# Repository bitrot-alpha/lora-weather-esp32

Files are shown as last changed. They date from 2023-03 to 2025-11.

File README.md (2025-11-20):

# lora-weather-esp32
Weather station with ESP32 and LoRa

This weather station is capable of measuring wind speed and direction, total rainfall, and current environmental conditions. Conditions include temperature, humidity, and barometric pressure. I put this together because I got interested in microclimate weather. Many rural areas in the United States do not have a weather station nearby, so the conditions you experience may not match what is shown on https://www.weather.gov/ or AccuWeather since the weather station may be over 20 miles away from you. A popular commercially available version of this project is the Ambient Weather WS-2902 (retail: $200 US). However, Ambient Weather does not publish what specific sensors they use in their product, so accuracy is questionable. The wireless range of the sensing unit to the "console" is also on the low end, about 300ft line of sight. On the higher end, there is the KestrelMet 6000 series (starting at $800 US) of stations which is more in line with the capabilities of this project with the option for LTE connectivity (overkill for my purposes).

The system consists of a base station outside where all the sensors are mounted, and a receiver unit that displays the current reading on an LCD. The receiver also connects to wifi and serves a basic webpage with current readings. Webpage (local network only) at http://weather-station.local/

### Current Features
* Atmospheric conditions
  * Temperature - +/-0.5C (BME280)
  * Relative Humidity - +/-2% (SHT31-D)
  * Barometric Pressure - +/- 1.5Pa/K (BME280)
* Wind Speed & Direction (cup-type anemometer, 16 direction weather vane)
* Accumulated Rainfall (tipping bucket type) - seems to be highly accurate. I am getting comparable data to my local weather station. The mounting is susceptible to vibration, so the mast needs to be solidly anchored.
* Self-powered base station
  * 2 watt solar "array"
  * 3000mAh/11Wh battery
  * The only outages I have gotten with this configuration are from user error (forgetting to plug back in the solar panel wires). Have not gotten a dead battery from overcast/rainy days yet.
* Long range wireless connection (untested for "max range" but since this is Arduino, we can configure for more power/signal robustness if needed)
* **NEW** view current weather data from web browser (November 2025)
### Planned Additions (Wishlist)
* ~~Add SHT31 sensor for more accurate humidity data. The BME280 is not designed for "condensing" environments (don't get it wet..)~~ SHT31-D installed
  * Document waterproofing methods for the electronics
* Historical data with LittleFS storage. Store a week or more of data.
* Graph the data via web browser. Possible with a library like [Chart.js](https://www.chartjs.org/)
* Add more configuration capability over LoRa
  * Send calibration commands from indoor receiver
  * Set the time with NTP. Have the data reset at 3AM instead of whenever system reset + 48hrs have passed.

## Hardware
* [MCU Board][mcu] - Heltec WiFi LoRa 32 v3 (ESP32-S3 with SX1262 LoRa modem and SSD1306 0.96" OLED Display)   
* Wind Speed, Wind Direction, and Rain Gauge kit - Available from [Argent Data][argent data kit] or [SparkFun][sparkfun kit].  
* [HiLetGo BME280 breakout board][bme280 board] - measures temperature, humidity, and pressure. The humidity sensor on this device failed after a year (not meant for condensing environments, i.e. fog). If you're building a project like this, go with the cheaper BMP280.
* [HiLetGo SHT31-D breakout board][sht31 board] - measures temperature and humidity. I added it just for the humidity sensing. I suppose according to the specs, the SHT is more accurate for temperature too.
* [DFRobot MPPT 6V Solar Panel Controller][dfrobot board] - charges a LiPo battery with the help of the sun  
* [Ambient Weather Solar Shield/Stevenson Screen][atmo sensor housing] - I didn't want to 3D print anything major for this project, so I found this on Amazon.  
* [2x 5V 1W Solar Panel][solar panel]  
* [3.7V 3000mah LiPo battery][lipo battery]  
* [RJ11 Jack Breakouts][rj11 jacks] - The wind and rain sensor kit uses RJ11 connectors.  
* [Generic LCD2004A LCD module with I2C][lcd i2c module] - for the indoor display.  

[mcu]: https://heltec.org/project/wifi-lora-32-v3/
[sparkfun kit]: https://www.sparkfun.com/products/15901
[argent data kit]: https://www.argentdata.com/catalog/product_info.php?products_id=145
[bme280 board]: https://www.amazon.com/gp/product/B01N47LZ4P/
[sht31 board]: https://www.amazon.com/dp/B0CN32WXJY
[dfrobot board]: https://www.amazon.com/gp/product/B07MML4YJV/
[atmo sensor housing]: https://www.amazon.com/gp/product/B09T4QDBN3/
[solar panel]: https://www.amazon.com/dp/B0BML3PR4Z
[lipo battery]: https://www.amazon.com/dp/B0DK5BBKM5
[rj11 jacks]: https://www.amazon.com/dp/B09HTRKRSH
[lcd i2c module]: https://www.amazon.com/dp/B01GPUMP9C/

## Tools
* [PlatformIO IDE based on VS Code][platformio]   
* [For small tests: Arduino IDE][arduino]   
* [The wonderful RadioLib for using LoRa][radiolib]   
* [ESPAsyncWebServer][asyncwebserver]   

[platformio]: https://platformio.org/platformio-ide
[arduino]: https://www.arduino.cc/en/software
[radiolib]: https://github.com/jgromes/RadioLib
[asyncwebserver]: https://github.com/ESP32Async/ESPAsyncWebServer/wiki

## Photos
These are a bit old, so they don't reflect the most current setup. I have since modified the system with a larger 3000mAh lithium cell and added another solar panel for increased runtime. I *think* the charge should last for more than a couple overcast days now.
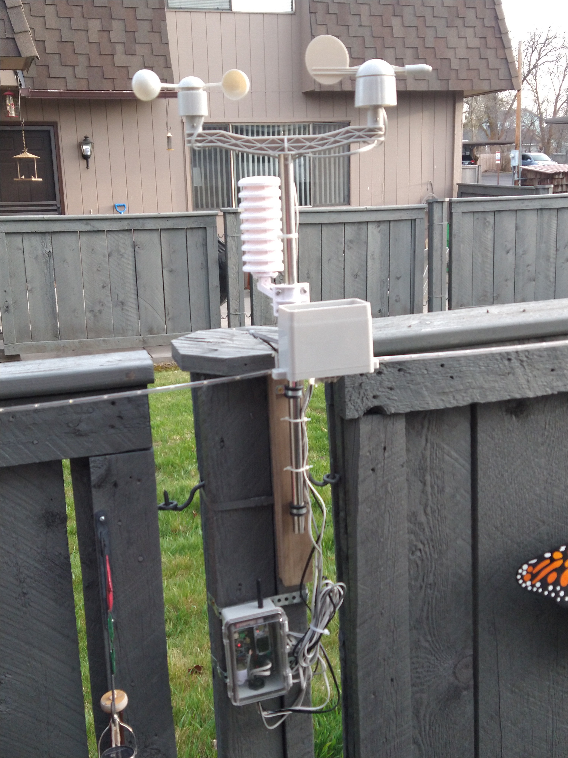
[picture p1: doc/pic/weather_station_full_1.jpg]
station1

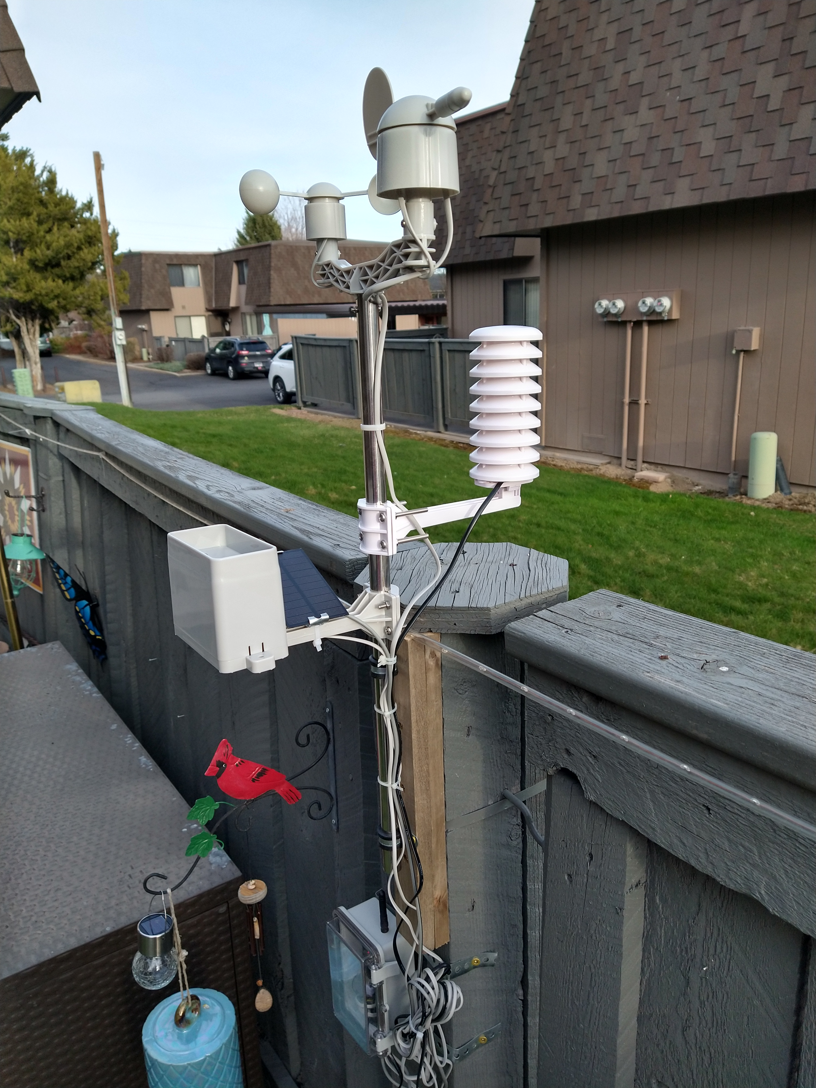
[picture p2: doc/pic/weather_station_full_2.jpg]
station2

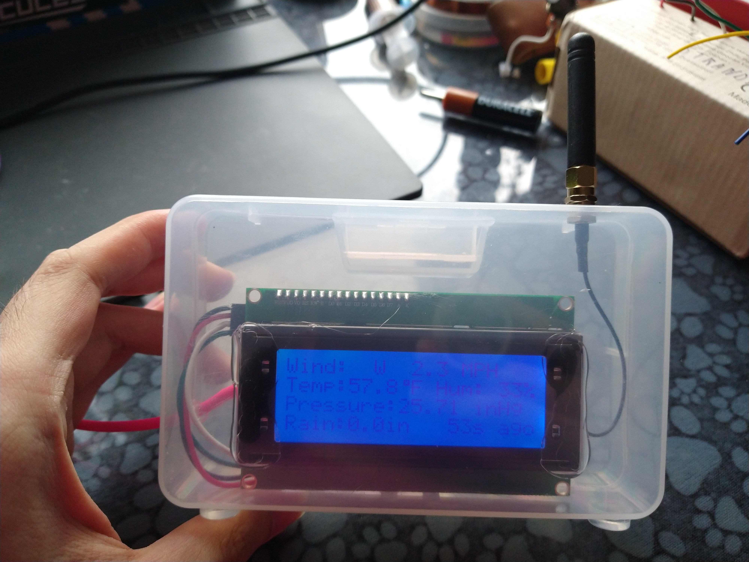
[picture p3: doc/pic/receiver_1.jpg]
receiver1

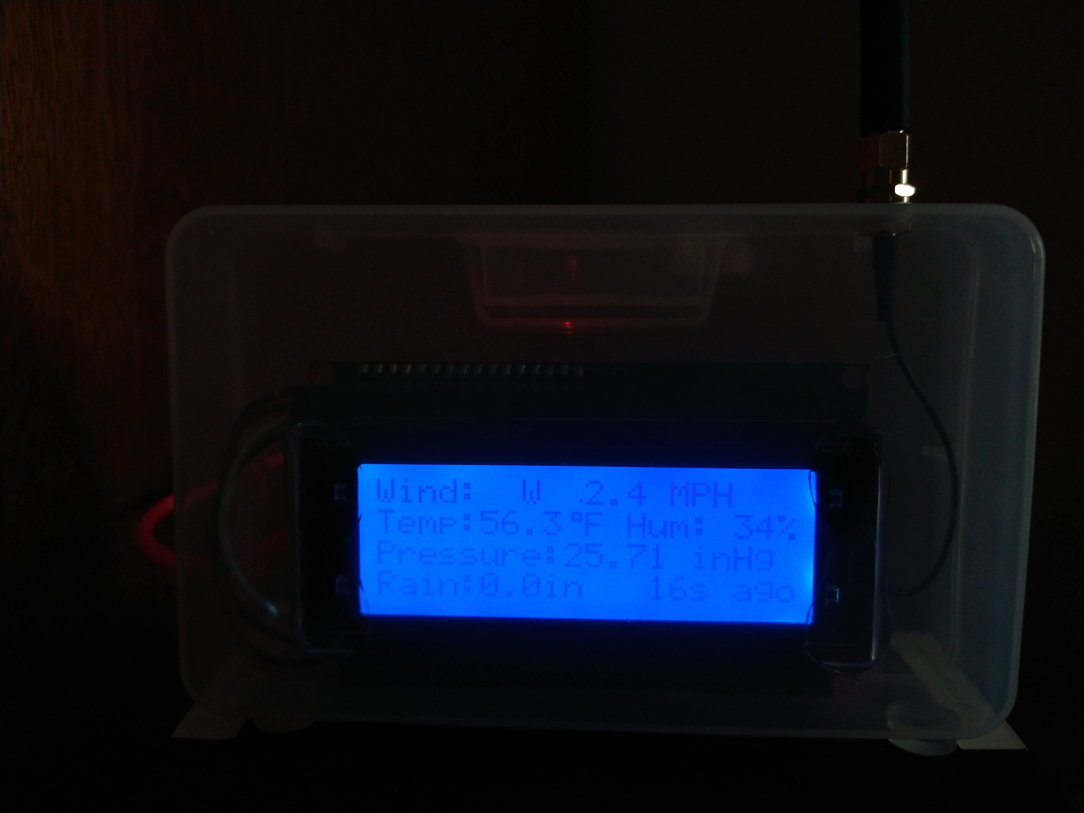
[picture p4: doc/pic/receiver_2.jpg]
receiver2

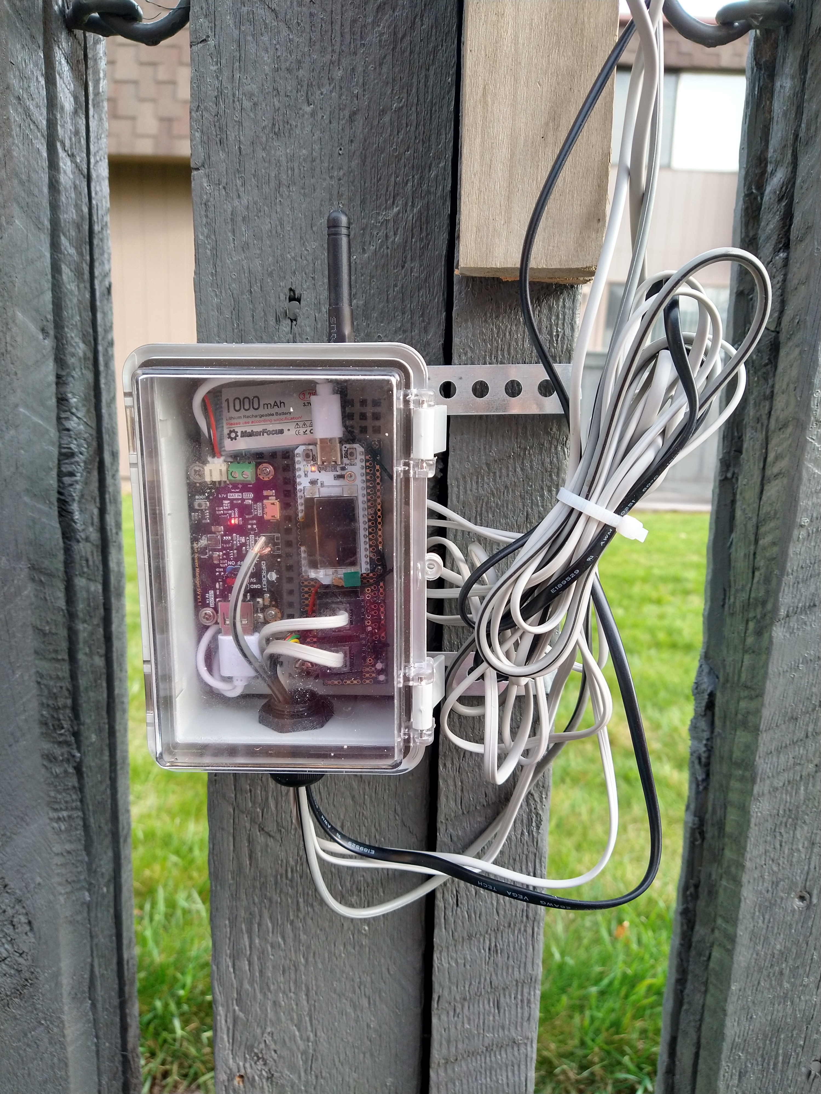
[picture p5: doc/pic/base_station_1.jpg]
bstation1

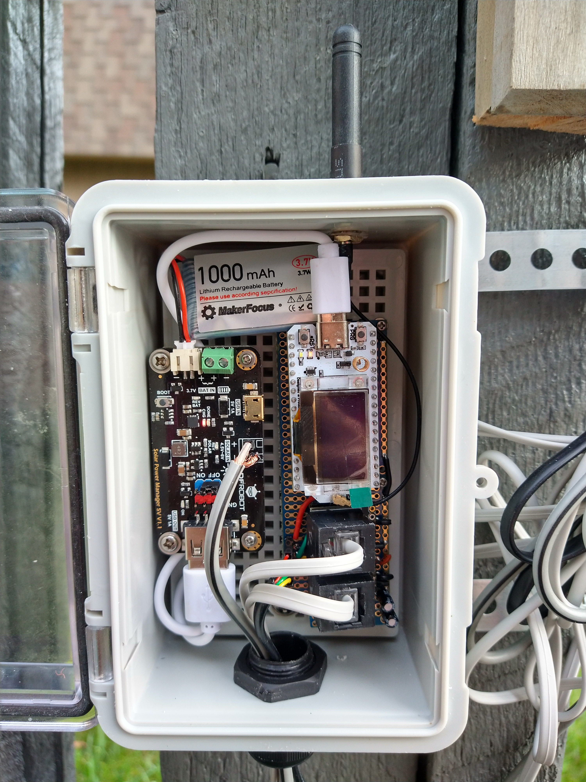
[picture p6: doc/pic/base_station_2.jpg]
bstation2


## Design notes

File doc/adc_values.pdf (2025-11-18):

Sheet1

Heading, Degrees | Hdg, Dir | Resistance | Voltage (Vcc=5V, r=10k) Voltage (Vcc=3.3V, r=10K, 50mV droop)
0.0 | N | 33.00E+03 | 3.84 | 2.494
22.5 | NNE | 6.57E+03 | 1.98 | 1.289
45.0 | NE | 8.20E+03 | 2.25 | 1.464
67.5 | ENE | 891.00E+00 | 0.41 | 0.266
90.0 | E | 1.00E+03 | 0.45 | 0.295
112.5 | ESE | 688.00E+00 | 0.32 | 0.209
135.0 | SE | 2.20E+03 | 0.90 | 0.586
157.5 | SSE | 1.41E+03 | 0.62 | 0.402
180.0 | S | 3.90E+03 | 1.40 | 0.912
202.5 | SSW | 3.14E+03 | 1.19 | 0.777
225.0 | SW | 16.00E+03 | 3.08 | 2.000
247.5 | WSW | 14.12E+03 | 2.93 | 1.903
270.0 | W | 120.00E+03 | 4.62 | 3.000
292.5 | WNW | 42.12E+03 | 4.04 | 2.626
315.0 | NW | 64.90E+03 | 4.33 | 2.816
337.5 | NNW | 21.88E+03 | 3.43 | 2.231
ESP32 ADC value (calc.) | -2.00% | 2.00%
3095 | 3033 | 3157 | Vout = Vcc*(R1/(R1+R2))
1599 | 1567 | 1631
1817 | 1781 | 1853 | ADCnum = (Vout/3.3) * ((2^adc_bits) - 1)
330 | 323 | 337
367 | 359 | 374
260 | 254 | 265
727 | 713 | 742
498 | 488 | 508
1132 | 1109 | 1154
964 | 944 | 983
2482 | 2432 | 2531
2361 | 2314 | 2408
3723 | 3648 | 3797
3259 | 3194 | 3324
3495 | 3425 | 3564
2768 | 2713 | 2823
check these out:
https://github.com/e-tinkers/esp32-adc-calibratehttps://docs.espressif.com/projects/esp-idf/en/stable/esp32/api-reference/peripherals/adc_calibration.html

Sheet1

font for LCD

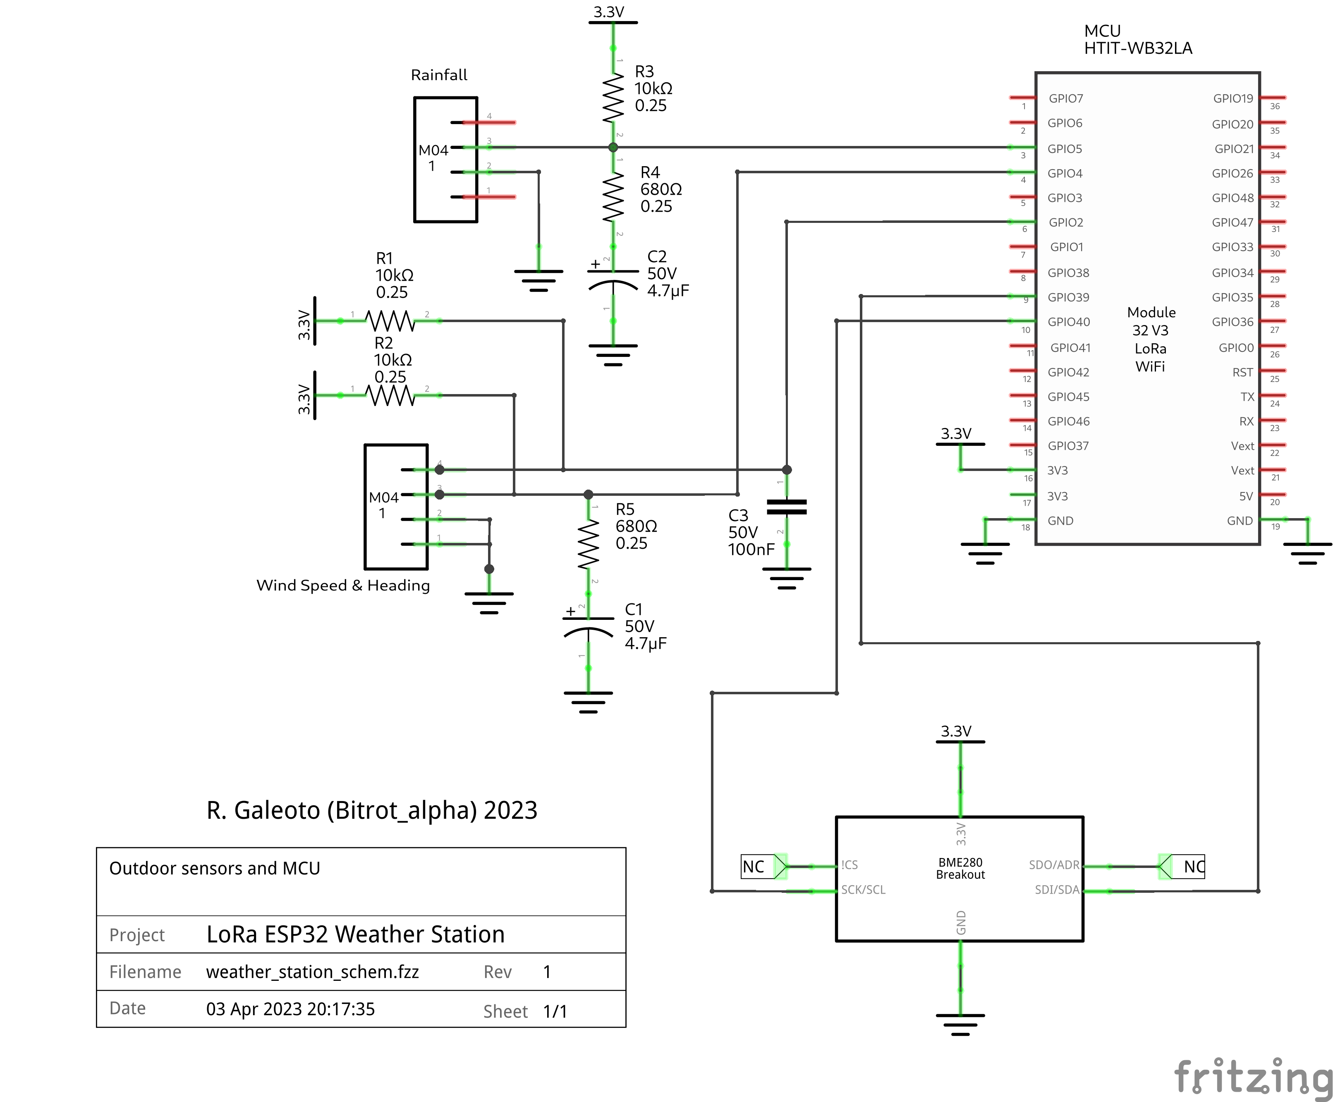
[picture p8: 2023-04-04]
doc/weather_station_schem_export.png

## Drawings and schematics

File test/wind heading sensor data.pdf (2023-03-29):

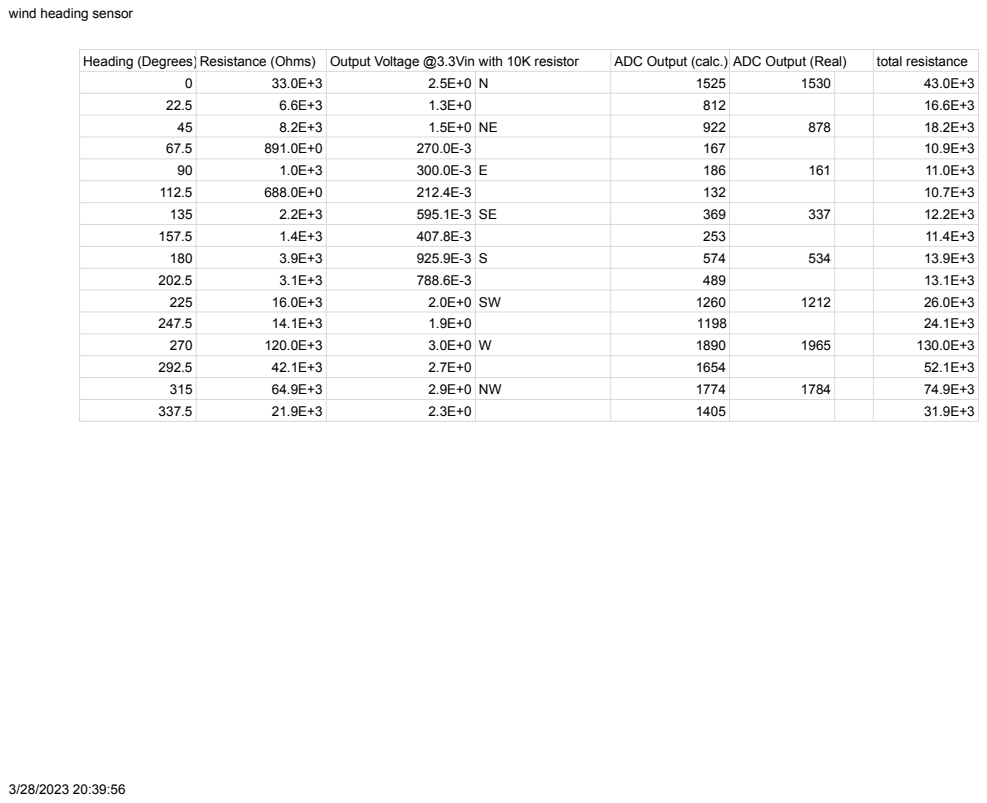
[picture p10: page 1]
Heading (Degrees) Resistance (Ohms) Output Voltage @3.3Vin with 10K resistor; ADC Output (calc.) ADC Output (Real); total resistance

wind heading sensor

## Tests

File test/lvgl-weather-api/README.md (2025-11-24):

# LVGL Demo with SHT31-D

This is a demo of LVGL on an ST7796S 4.0 inch SPI display with an SHT31-D sensor.  
The red board with SD card slot, https://www.lcdwiki.com/4.0inch_SPI_Module_ST7796  
It shows loading images and dynamic text updates with the SHT sensor values.  
This uses a standard ESP32 dev board, NOT the Heltec board with the LoRa modem.  

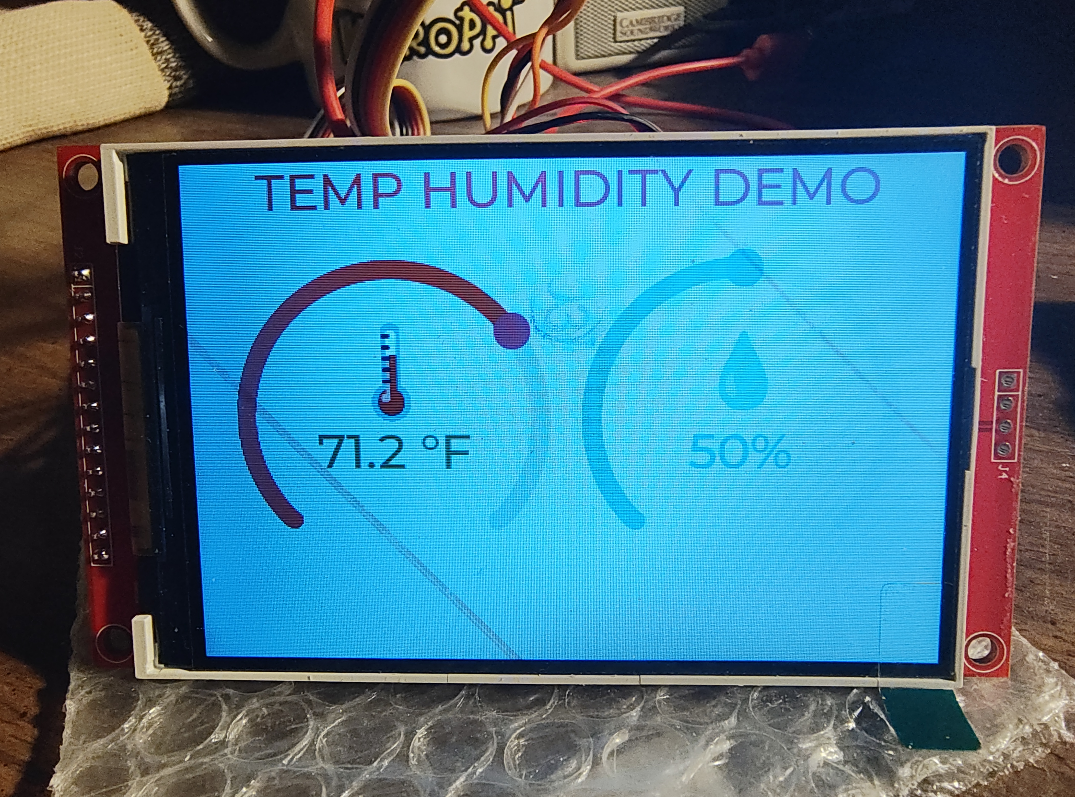
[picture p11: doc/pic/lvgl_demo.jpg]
ST7796S display with temp + humidity demo


## Display Pins
```
DISPLAY -> ESP32 (DOIT Devkit V1, not Heltec board)
CS ----------- HSPI_CS0 (GPIO15)
RESET -------- GPIO32
DC/RS -------- GPIO33
SDI (MOSI) --- HSPI_MOSI (GPIO13)
SCK ---------- HSPI_CLK (GPIO14)
LED ---------- GPIO27 or +3V3 for no backlight adjustment
SDO (MISO) --- HSPI_MISO (GPIO12)
```

## SHT31-D Pins
```
SHT -> ESP32
------------
SDA -> SDA (GPIO21)
SCL -> SCL (GPIO22)
```
## Board Pinout
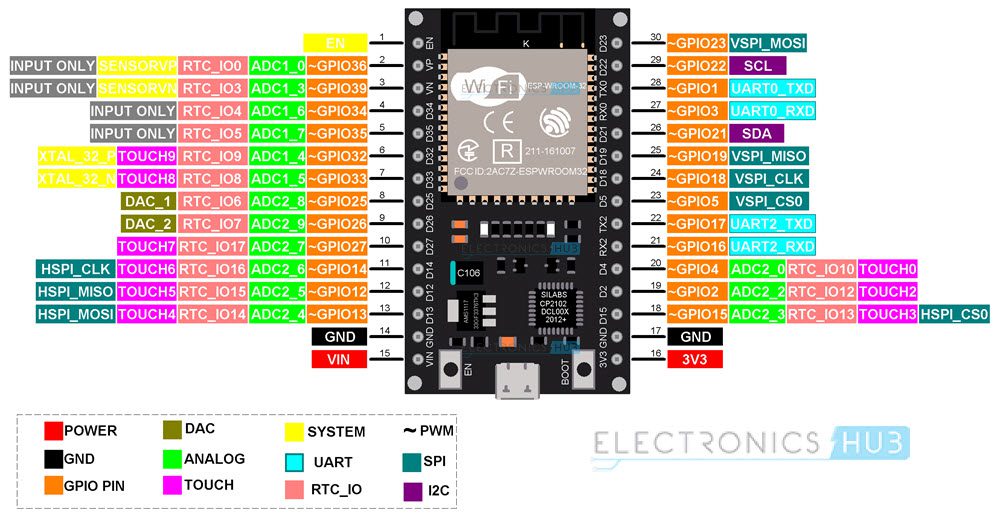
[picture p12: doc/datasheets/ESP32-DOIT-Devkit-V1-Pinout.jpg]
ESP32 DOIT Devkit V1 pinout from ElectronicsHub


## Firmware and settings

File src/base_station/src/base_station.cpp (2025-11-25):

// Author: Bitrot_alpha, nseidle
// Weather Station and LoRa transmitter
//    Much of the wind and rain sensor code is based off of nseidle's project
//    located at https://github.com/sparkfun/Wimp_Weather_Station
//    Buy Nate a beer if you see him ("beerware license")
//#define USE_OLD_VAL

#include <Arduino.h>
#include "lora_data.h"
#include "heltec_board_pins.h"
#ifndef USE_OLD_VAL
//#include "adc_lut.h"
#endif
#include <RadioLib.h>
#include <Wire.h>
#include <Adafruit_Sensor.h>
#include <Adafruit_BME280.h>
#include <SHTSensor.h>
#include <ESP32Time.h> //onboard rtc library

//Sleep time (50 seconds)
const unsigned int SLEEP_TIME = 50 * 1000000;
//Number of hours to keep persistent data like rainfall before resetting
const unsigned int RESET_MAX = 48;

//Values that are kept when sleeping and waking up
RTC_DATA_ATTR uint16_t bootcycles = 0;
//RTC_DATA_ATTR unsigned long lastWakeup = 0;
RTC_DATA_ATTR unsigned long lastWakeupMillis = 0;
RTC_DATA_ATTR float raincount = 0.0F;

//Use the onboard RTC to keep track of time
ESP32Time rtc;

// **** LoRa setup section ****
//Set this to be the same on both base station and receivers
uint16_t STATION_KEY = 0xF00D;
lora_packet_t dataPacket = 
{
  //dummy values for testing
  //0xF00D, 5, 5.5F, 81.4F, 70.5F, 25.83F
};
SX1262 radio = new Module(LORA_NSS, LORA_DIO, LORA_RST, LORA_BSY);
// ****** END LoRa Setup ******

// **** SENSORS SECTION ****
//un-comment to get serial readout of barometer
//#define CAL_BAROMETER
//un-comment to get serial readout of wind heading
//#define WIND_DEBUG
//comment out to keep SI units instead of converting to US customary
#define CONV_IMPERIAL

Adafruit_BME280 bme;
SHTSensor sht(SHTSensor::SHT3X);

const uint8_t SDA_PIN = 39;
const uint8_t SCK_PIN = 40;
const uint8_t BME_ADDRESS = 0x76;
// calibrate the pressure value using an offset
// as demonstrated in this video: https://www.youtube.com/watch?v=Wq-Kb7D8eQ4
const float PRESSURE_OFFSET = -1.65F;
//feet to meters: divide by 3.2[...]
//delete the divide portion if you're not using US customary units
const float ALTITUDE_METERS = 1346.0F / 3.28084F;

//anemometer pin
const uint8_t WIND_SPD_PIN = 4;
//wind heading pin
const uint8_t WIND_DIR_PIN = 2;
//if your anemometer is bouncy, set this to something other than 1 to "calibrate" it
const uint8_t BOUNCE_COMPENSATION = 2;
//rain gauge pin
const uint8_t RAIN_GAUGE_PIN = 5;
const gpio_num_t RAIN_GAUGE_ESP_PIN = GPIO_NUM_5;

uint16_t heading_raw = 0;

//globals for tracking wind
long lastWindCheck = 0;
volatile long lastWindIRQ = 0;
volatile uint8_t windRevs = 0;

volatile long raintime = 0;
long raininterval = 0;
long rainlast = 0;
// ****** END SENSORS SECTION ******

void wind_spd_IRQ()
{
  if (millis() - lastWindIRQ > 10) // Ignore switch-bounce glitches less than 10ms (142MPH max reading) after the reed switch closes
	{
		lastWindIRQ = millis(); //Grab the current time
		windRevs++; //There is 1.492MPH (2.4 km/h) for each click per second.
	}
}

float get_wind_speed()
{
	float deltaTime = millis() - lastWindCheck;

	deltaTime /= 1000.0F; //Convert to seconds

	float windSpeed = (float)(windRevs / BOUNCE_COMPENSATION) / deltaTime;

	windRevs = 0; //Reset and start watching for new wind
	lastWindCheck = millis();

  #ifdef CONV_IMPERIAL
  windSpeed *= 1.492;
  #else
  windSpeed *= 2.4;
  #endif

	return(windSpeed);
}

uint16_t getADCValue()
{
  //multisampling
  uint16_t adc_value = 0;
  for (int i = 0; i < 16; i++) 
  {
    #ifdef USE_OLD_VAL
    adc_value += analogRead(WIND_DIR_PIN);
    #else
    //use ESP32-S3 factory calibration with analogReadMillivolts();
    adc_value += analogReadMilliVolts(WIND_DIR_PIN);
    #endif
    delay(2);
  }
  adc_value /= 16;

  return adc_value;
}

const uint8_t determineHeading(uint16_t adc_value)
{ 
  #ifdef USE_OLD_VAL
  //OLD VALUES (uncalibrated)
  //the headings go clockwise every 45 degrees from N (0 degrees) to NW (315 degrees)
  //bounds are 5% either side of what the ADC value should be
  if (adc_value >= 1454 && adc_value <= 1607)
    return 0;
  if (adc_value >= 834 && adc_value <= 922)
    return 1;
  if (adc_value >= 153 && adc_value <= 169)
    return 2;
  if (adc_value >= 320 && adc_value <= 354)
    return 3;
  if (adc_value >= 507 && adc_value <= 561)
    return 4;
  if (adc_value >= 1151 && adc_value <= 1273)
    return 5;
  if (adc_value >= 1867 && adc_value <= 2063)
    return 6;
  if (adc_value >= 1695 && adc_value <= 1873)
    return 7;

  return 8;
  #else
  //headings go clockwise every 22.5 degrees from N (0 deg) to NNW (337.5 deg)
  //bounds are plus minus 75mV, sadly some overlap
  if (adc_value >= 2458 && adc_value <= 2598)    return 0;
  if (adc_value >= 1233 && adc_value <= 1383)    return 1;
  if (adc_value >= 1412 && adc_value <= 1562)    return 2;
  if (adc_value >= 225 && adc_value <= 375)    return 4;
  if (adc_value >= 195 && adc_value <= 345)    return 3;
  if (adc_value >= 137 && adc_value <= 287)    return 5;
  if (adc_value >= 520 && adc_value <= 670)    return 6;
  if (adc_value >= 333 && adc_value <= 483)    return 7;
  if (adc_value >= 851 && adc_value <= 1001)    return 8;
  if (adc_value >= 714 && adc_value <= 864)    return 9;
  if (adc_value >= 1956 && adc_value <= 2106)    return 10;
  if (adc_value >= 1857 && adc_value <= 2007)    return 11;
  if (adc_value >= 2971 && adc_value <= 3121)    return 12;
  if (adc_value >= 2592 && adc_value <= 2742)    return 13;
  if (adc_value >= 2784 && adc_value <= 2934)    return 14;
  if (adc_value >= 2190 && adc_value <= 2340)    return 15;

  return 16;
  #endif
}

void rainIRQ()
// Count rain gauge bucket tips as they occur
// Activated by the magnet and reed switch in the rain gauge
{
	raintime = millis(); // grab current time
	raininterval = raintime - rainlast; // calculate interval between this and last event

	if (raininterval > 10) // ignore switch-bounce glitches less than 10mS after initial edge
	{
    #ifdef CONV_IMPERIAL
    raincount += 0.011; //Each dump is 0.011" of water
    #else
    raincount += 0.2794; //Each dump is 0.2794mm of water
    #endif

		rainlast = raintime; // set up for next event
	}
}



void print_wakeup_reason()
{
  esp_sleep_wakeup_cause_t wakeup_reason;

  wakeup_reason = esp_sleep_get_wakeup_cause();

  switch(wakeup_reason)
  {
    case ESP_SLEEP_WAKEUP_EXT0:
      Serial.println("Wakeup caused by external signal using RTC_IO");
      break;
    case ESP_SLEEP_WAKEUP_EXT1:
      Serial.println("Wakeup caused by external signal using RTC_CNTL");
      break;
    case ESP_SLEEP_WAKEUP_TIMER:
      Serial.println("Wakeup caused by timer");
      break;
    case ESP_SLEEP_WAKEUP_TOUCHPAD:
      Serial.println("Wakeup caused by touchpad");
      break;
    case ESP_SLEEP_WAKEUP_ULP:
      Serial.println("Wakeup caused by ULP program"); 
      break;
    default:
      Serial.printf("Wakeup was not caused by deep sleep: %d\r\n",wakeup_reason);
      break;
  }
}

void setup() 
{
  //increment our boot counter
  bootcycles++;

  //reset rain count every RESET_MAX hours-ish
  if ( bootcycles > (RESET_MAX * 60) )
  {
    bootcycles = 0;
    raincount = 0.0F;
  }

  if(esp_sleep_get_wakeup_cause() == ESP_SLEEP_WAKEUP_EXT0)
  {
    #ifdef CONV_IMPERIAL
    if (rtc.getMillis() - lastWakeupMillis > 10)
      raincount += 0.011;
    #else
    if (rtc.getMillis() - lastWakeupMillis > 10)
      raincount += 0.2794;
    #endif
    //record our last wakeup time
    //lastWakeup = rtc.getEpoch();
    lastWakeupMillis = rtc.getMillis();
  }
  
  Serial.begin(115200);
  print_wakeup_reason();

  //LoRa setup
  SPI.begin(LORA_SCK, LORA_MISO, LORA_MOSI);
  radio.reset();
  int16_t res = radio.begin(LORA_FREQ, LORA_BW, LORA_SF, LORA_CR);
  if(RADIOLIB_ERR_NONE != res)
  {
    //why is my white led blinking??
    //check here: https://jgromes.github.io/RadioLib/group__status__codes.html
    uint8_t ledOn = 0;
    pinMode(LED_BUILTIN, OUTPUT);

    while(1)
    {
      ledOn = ~ledOn;
      Serial.println("Could not init SX1262 radio!!!");
      Serial.printf("Code: %d\r\n", res);
      digitalWrite(LED_BUILTIN, ledOn);
      delay(500);
    }
  }
  radio.setOutputPower(LORA_TX_POWER);

  //setup wind sensors and rain gauge
  analogReadResolution(12);
  pinMode(WIND_DIR_PIN, ANALOG);
  pinMode(WIND_SPD_PIN, INPUT);
  attachInterrupt(WIND_SPD_PIN, wind_spd_IRQ, FALLING);
  attachInterrupt(RAIN_GAUGE_PIN, rainIRQ, FALLING);

  //I2C sensors setup
  Wire1.begin(SDA_PIN, SCK_PIN);
  if (!bme.begin(BME_ADDRESS, &Wire1) ) 
  {
    pinMode(LED_BUILTIN, OUTPUT);
    digitalWrite(LED_BUILTIN, 1);
    Serial.print("BME280 not found. Check wiring!\n");
    delay(5000);
    digitalWrite(LED_BUILTIN, 0);
    pinMode(LED_BUILTIN, INPUT);
    delay(1);
    //try again
    ESP.restart();
  }
  if (!sht.init(Wire1) )
  {
    pinMode(LED_BUILTIN, OUTPUT);
    digitalWrite(LED_BUILTIN, 1);
    Serial.print("SHT31 not found. Check wiring!\n");
    delay(5000);
    digitalWrite(LED_BUILTIN, 0);
    pinMode(LED_BUILTIN, INPUT);
    delay(1);
    //try again
    ESP.restart();
  }
  
  //setup the sensor for weather station scenario per datasheet section 3.5
  //see the Adafruit library "advanced_settings" example
  bme.setSampling(
                  Adafruit_BME280::MODE_FORCED,
                  Adafruit_BME280::SAMPLING_X1, // temperature
                  Adafruit_BME280::SAMPLING_X1, // pressure
                  Adafruit_BME280::SAMPLING_NONE, // humidity
                  Adafruit_BME280::FILTER_OFF
                 );
  //wait for 10 seconds to gather wind data
  delay(10000);

  // **** MAIN SECTION ****
  dataPacket.station_key = STATION_KEY;
  dataPacket.hours_up = bootcycles / 60;
  //bme measure
  //measurements are converted to US/Imperial units
  bme.takeForcedMeasurement();
  #ifdef CONV_IMPERIAL
  dataPacket.temperature = ( (bme.readTemperature() * 1.8F) + 32 );
  dataPacket.pressure = ( (bme.seaLevelForAltitude(ALTITUDE_METERS, bme.readPressure() * 0.01) + PRESSURE_OFFSET) / 33.86F);
  #else
  dataPacket.temperature = ( (bme.readTemperature() );
  dataPacket.pressure = ( bme.seaLevelForAltitude(ALTITUDE_METERS, bme.readPressure() * 0.01) + PRESSURE_OFFSET );
  #endif
  //dataPacket.humidity = bme.readHumidity();
  dataPacket.humidity = sht.getHumidity();

  //wind stuff
  heading_raw = getADCValue();
  dataPacket.wind_speed = get_wind_speed();
  dataPacket.wind_heading = determineHeading(heading_raw);
  #ifdef WIND_DEBUG
  Serial.printf("ADC: %d Heading: %d\r\n", heading_raw, dataPacket.wind_heading);
  #endif
  //rain gauge count
  dataPacket.rainfall = raincount;

	Serial.printf("\r\nsending packet\r\n");
  #ifdef CAL_BAROMETER
  Serial.printf("Barometer reading: %.2f hPa, %.2f inHg\r\n", dataPacket.pressure * 33.86F, dataPacket.pressure);
  Serial.printf("Offset: %.2f\r\n", PRESSURE_OFFSET);
  #endif
  radio.transmit((const uint8_t *) &dataPacket, sizeof(dataPacket));

  delay(100);
  Serial.printf("Processing done. Going to sleep now.\r\n");
  Serial.flush();
  radio.sleep(false);

  //set our last wakeup times
  //lastWakeup = rtc.getEpoch();
  lastWakeupMillis = rtc.getMillis();

  //sleep for a minute at a time
  //wakeup when the rain gauge triggers
  esp_sleep_enable_ext0_wakeup(RAIN_GAUGE_ESP_PIN, 0);
  esp_sleep_enable_timer_wakeup(SLEEP_TIME);
  esp_deep_sleep_start();
  // **** END MAIN SECTION ****
}

void loop()
{
  //should never get here because we're sleeping
}

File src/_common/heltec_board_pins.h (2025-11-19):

// Author: Bitrot_alpha
// Pins of Heltec Wifi LoRa 32 (V3) board
// see https://resource.heltec.cn/download/WiFi_LoRa_32_V3/HTIT-WB32LA(F)_V3.1_Schematic_Diagram.pdf

#ifndef _HELTEC_BOARD_PINS_H
#define _HELTEC_BOARD_PINS_H

//lora module pins on Heltec Wifi LoRa V3 board
#define LORA_NSS     8
#define LORA_DIO    14
#define LORA_RST    12
#define LORA_BSY    13
#define LORA_MOSI   10
#define LORA_MISO   11
#define LORA_SCK     9

//OLED display pins
#define VEXT_CTRL   36
#define OLED_PWR    VEXT_CTRL
#define OLED_SDA    17
#define OLED_SCL    18
#define OLED_RST    21

//PRG button ("USER_Key")
#define BTN_ONBOARD     0
//onboard LED is already in the Arduino board def.
//#define LED_BUILTIN   35

//Battery charger circuit
#define ADC_CTRL    37
#define VBAT_PIN     1

#endif

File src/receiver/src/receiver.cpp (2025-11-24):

// Author: Bitrot_alpha
// Weather station receiver
// prints out data from LoRa to 2004A LCD
// NEW: data reporting (simple) on http server!
// Pairs with base_station to display weather data

#include <Arduino.h>
#include <Wire.h>
#include <LiquidCrystal_PCF8574.h>
#include <RadioLib.h>
#include "heltec_board_pins.h"
#include "lora_data.h"
#include "lcd_chars.h"
#include <Preferences.h>
#include <math.h>
//wifi stuff
#include <NTPClient.h>
#include <WiFi.h>
#include <WiFiUdp.h>
#include <lwip/inet.h>
//webserver stuff
#include <AsyncTCP.h>
#include <ESPAsyncWebServer.h>
#include <LittleFS.h>
#include <ESPmDNS.h>

//enable WPS or use hardcoded wifi credentials
#define USE_WPS
//SI/US customary units toggle, comment out to use SI units
#define USE_IMPERIAL

#ifndef USE_WPS
  #include "wifi_credentials.h"
#else
  #include "esp_wps.h"
#endif

//functions
ICACHE_RAM_ATTR void loraPacketReceived(void);
void processPacket();
float getDewPoint(float temp, float hum);
char * getSimpleData();
void WiFiEvent(WiFiEvent_t event, arduino_event_info_t info);
void wpsStart();
void wpsStop();
//------------------------------------

const char HOSTNAME[] = "WeatherStation";
const char MDNS_NAME[] = "weather-station";

//LoRa setup section
SX1262 radio = new Module(LORA_NSS, LORA_DIO, LORA_RST, LORA_BSY);
const uint16_t STATION_KEY = 0xF00D;
volatile bool flagReceived = false;
//END LoRa setup section

//I2C Setup here
const uint8_t SDA_PIN = 41;
const uint8_t SCK_PIN = 42;
const uint8_t I2C_ADDR = 0x27;

LiquidCrystal_PCF8574 lcd(I2C_ADDR);

char wind_str[21] = "";
char temperature_str[13] = "";
char humidity_str[11] = "";
char pressure_str[21] = "";
char rainfall_str[21] = "";

static lora_packet_t receivedData =
{
  //dummy values for testing
  //0xF00D, 3, 5.5F, 75.3F, 26.3F, 25.83F, 0.422F
};

//time display tracking
unsigned long prevDisplayTime = 0;
unsigned long lastUpdate = 0;
unsigned long raw_sec = 0;
unsigned long upd_sec = 0;
unsigned long upd_min = 0;

const char * heading_map[] = 
{
  "N\0", "NNE\0", "NE\0", "ENE\0",
  "E\0", "ESE\0", "SE\0", "SSE\0",
  "S\0", "SSW\0", "SW\0", "WSW\0",
  "W\0", "WNW\0", "NW\0", "NNW\0",
  "X\0"  
};

//get the time from network
//refresh every 3 hours
//arg 3 is time offset (can use it for time zone) and arg 4 is refresh interval in milliseconds
WiFiUDP ntpUDP;
NTPClient timeClient(ntpUDP, "north-america.pool.ntp.org", (-7 * 3600), ( (3 * 3600 * 1000) + 1000) );

Preferences savedData;
//web server stuff
AsyncWebServer server(80);

void setup()
{
  pinMode(LED_BUILTIN, OUTPUT);
  digitalWrite(LED_BUILTIN, 0);

  savedData.begin("wifidata", false);
  Serial.begin(115200);
  LittleFS.begin(true);
  SPI.begin(LORA_SCK, LORA_MISO, LORA_MOSI);
  Wire1.begin(SDA_PIN, SCK_PIN);  // custom i2c port on ESP
  lcd.begin(20,4, Wire1);

  lcd.createChar(1, (uint8_t *)degree_char); // degree character for LCD
  lcd.createChar(2, (uint8_t *)deg_f_char);  // degF character for LCD
  lcd.createChar(3, (uint8_t *)deg_c_char);  // degC character for LCD
  lcd.createChar(4, (uint8_t *)in_char);     // in character for LCD
  lcd.createChar(5, (uint8_t *)hg_char);     // Hg character for LCD
  lcd.createChar(6, (uint8_t *)mm_char);     // mm character for LCD
  lcd.createChar(7, (uint8_t *)hpa_char);     // hPa character for LCD
  lcd.setBacklight(255);
  //reset LCD
  //don't call clear() every refresh to avoid flashing
  lcd.home();
  lcd.clear();

  //lora init section
  int16_t res = radio.begin(LORA_FREQ, LORA_BW, LORA_SF, LORA_CR);
  if(RADIOLIB_ERR_NONE != res)
  {
    uint8_t ledOn = 0;
    while(1)
    {
      ledOn = ~ledOn;
      Serial.println("Could not init SX1262 radio!!!");
      Serial.printf("Code: %d\r\n", res);
      digitalWrite(LED_BUILTIN, ledOn);
      delay(500);
    }
  }
  radio.setOutputPower(LORA_TX_POWER);

  WiFi.setHostname(HOSTNAME);
  #ifdef USE_WPS
  pinMode(0,INPUT_PULLUP); //set PRG button as an input
  WiFi.onEvent(WiFiEvent);
  WiFi.mode(WIFI_MODE_STA);
  if(savedData.getBool("WifiIsSetup") == true)
    WiFi.begin();
  #else
  WiFi.begin(WIFI_SSID, WIFI_PASSWORD);
  #endif
  //wait 5 seconds for WiFi
  delay(5000);
  if(WiFi.status() == WL_CONNECTED)
  {
    timeClient.begin();
  }

  if(MDNS.begin(MDNS_NAME))
    Serial.println("MDNS start broadcast");
  
  server.on("/", HTTP_GET, [](AsyncWebServerRequest *request)
  {
      request->send(200, "text/plain", getSimpleData());
  });
  
  server.onNotFound([](AsyncWebServerRequest *request)
  {
    request->send(404, "text/plain", "404: Not found");
  });

  server.begin();

  WiFi.setSleep(true);

  radio.setDio1Action(loraPacketReceived);
  radio.startReceive();

  Serial.printf("Setup done!\r\n");
}

void loop()
{
  if(flagReceived)
  {
    processPacket();
  }

  unsigned long now = millis();
  //wait 1 second between outputs to display
  if(now - prevDisplayTime > 1000)
  {
    prevDisplayTime = now;
    raw_sec = (now - lastUpdate) / 1000;
    upd_sec = raw_sec % 60;
    upd_min = (raw_sec / 60) % 60;

    #ifdef USE_IMPERIAL
    //use the width part of the format specifier well since we're not calling clear() every time
    snprintf(wind_str, 21, "Wind: %3s %5.1f MPH\0", heading_map[receivedData.wind_heading], receivedData.wind_speed);
    snprintf(temperature_str, 14, "Temp:%5.1f\02\0", receivedData.temperature);
    snprintf(humidity_str, 11, " Hum:%3.0f%%\0", receivedData.humidity);
    snprintf(pressure_str, 21, "Prs:%5.2f\04\05 %2d:%02dago\0", receivedData.pressure, upd_min, upd_sec);
    snprintf(rainfall_str, 21, "Rain:%5.2f\04 last %2dh\0", receivedData.rainfall, receivedData.hours_up);
    #else
    //use the width part of the format specifier well since we're not calling clear() every time
    snprintf(wind_str, 21, "Wind: %3s %5.1f kph\0", heading_map[receivedData.wind_heading], receivedData.wind_speed);
    snprintf(temperature_str, 14, "Temp:%5.1f\03\0", receivedData.temperature);
    snprintf(humidity_str, 11, " Hum:%3.0f%%\0", receivedData.humidity);
    snprintf(pressure_str, 21, "Prs:%5.2f\07 %2d:%02dago\0", receivedData.pressure, upd_min, upd_sec);
    snprintf(rainfall_str, 21, "Rain:%4.0f\06 last %2dh\0", receivedData.rainfall, receivedData.hours_up);
    #endif

    lcd.home();
    lcd.print(wind_str);
    lcd.setCursor(0,1);
    lcd.print(temperature_str);
    lcd.print(humidity_str);
    lcd.setCursor(0,2);
    lcd.print(pressure_str);
    lcd.setCursor(0,3);
    lcd.print(rainfall_str);

    if(WiFi.status() != WL_CONNECTED)
    {
      //blink the white led here?
    }
    else
    {
      timeClient.update();
    }

    #ifdef USE_WPS
    if (digitalRead(0) == 0)
    {
      wpsStart();
    }
    #endif
  }
}

ICACHE_RAM_ATTR void loraPacketReceived(void)
{
  flagReceived = true;
}
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

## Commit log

2023-03-28 Wind Heading sensor example
2023-03-29 Wind Heading - added heading output and comment about ADC
2023-03-29 Anemometer demo code and wind heading sensor data
2023-03-29 BME280 Atmospheric sensor demo code
2023-04-02 Atmo Sensor Demo - Corrected units designation in serial monitor
    [atmo_sensor_units.ino]
2023-04-02 Atmo sensor tests - made serial monitor a #define
2023-04-02 Changed atmo sensor sampling mode to save power, added atmo sensor datasheet
2023-04-02 Created combined wind sensors test and increased display size of wind heading example
2023-04-02 Tweaked combined wind sensors to make more sense
2023-04-02 PCF8574 test - serial output now shows configured I2C address
2023-04-02 LCD Dynamic test - print wind sensor values
2023-04-04 Finished first revision of weather station schematic
    [weather_station_schem.fzz]
2023-04-23 Basic wireless functions done
    Now for power saving on base station
2023-04-25 Base station - code cleanup and added pressure calibration offset
2023-05-05 Cleanup and correct documentation comments
    [base_station.ino, receiver.ino]
2025-11-08 Update README with new library link and fix receiver.ino
    [receiver.ino]
2025-11-09 fedora is stupid sometimes
    Update base_station.ino and add barometer calibration serial readout
2025-11-15 Add more precise heading reading with calibrated ADC
    added spreadsheet to /doc with ADC value calculations (adc_values.ods)
    ADC needs to be calibrated with either the built-in efuse values or a
    LUT. I'm using a LUT that I generated with https://github.com/e-tinkers/esp32-adc-calibrate
    See my fork for an improved version that works with the Heltec board
    (you will need an MCP4725 DAC as the ESP32-S3 lacks an on-chip DAC)
    [adc_values.ods]
2025-11-18 Migrate to PlatformIO and RadioLib
    Reset instead of halt when BME280 is 'missing'
    [base_station.cpp, receiver.cpp]
2025-11-18 Update README.md
    Wow this looked awful sparse for how long?
    Added current features and extended description.
2025-11-18 Correct ADC calculations
    [adc_values.ods]
2025-11-19 Create heltec_board_pins.h, re-calibrate base_station wind headings
2025-11-20 Switch to SHT31, use Adafruit sea level pressure function
    Finish implementing SI units code (CONV_IMPERIAL define)
2025-11-20 Turn on LED if I2C sensors not connected
2025-11-24 Add LVGL demo to test/esp32-lvgl/
2025-11-24 Add lvgl demo pic and ESP32 DOIT pinout
2025-11-24 Create LVGL demo README.md in /test/esp32-lvgl/
2025-11-24 Add TFT time/temperature demo
2025-11-25 Use factory ADC calibration instead of LUT on base_station
2025-11-25 widen tolerances on determineHeading()
    [adc_values.ods]
2025-11-25 'Calibrated' wind vane values
